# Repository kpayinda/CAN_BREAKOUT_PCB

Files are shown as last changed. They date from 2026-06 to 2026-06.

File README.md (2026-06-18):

# CAN Bus Development Board

A general-purpose breakout and development board featuring the **MCP2562FDT** CAN transceiver, designed for testing and system integration.

## Key Features
* **Transceiver:** MCP2562FDT-E/SN (supports CAN FD up to 5 Mbps).
* **Power Rails:** Dual-rail design ($V_{DD} = 5\text{V}$ for bus, $V_{IO} = 3.3\text{V}$ for logic compatibility).
* **Protection:** On-board TVS diodes for ESD protection and space for a Common-Mode Choke.
* **Termination:** Includes optional split termination ($2 \times 60\,\Omega$ with a center-tapped capacitor to GND).

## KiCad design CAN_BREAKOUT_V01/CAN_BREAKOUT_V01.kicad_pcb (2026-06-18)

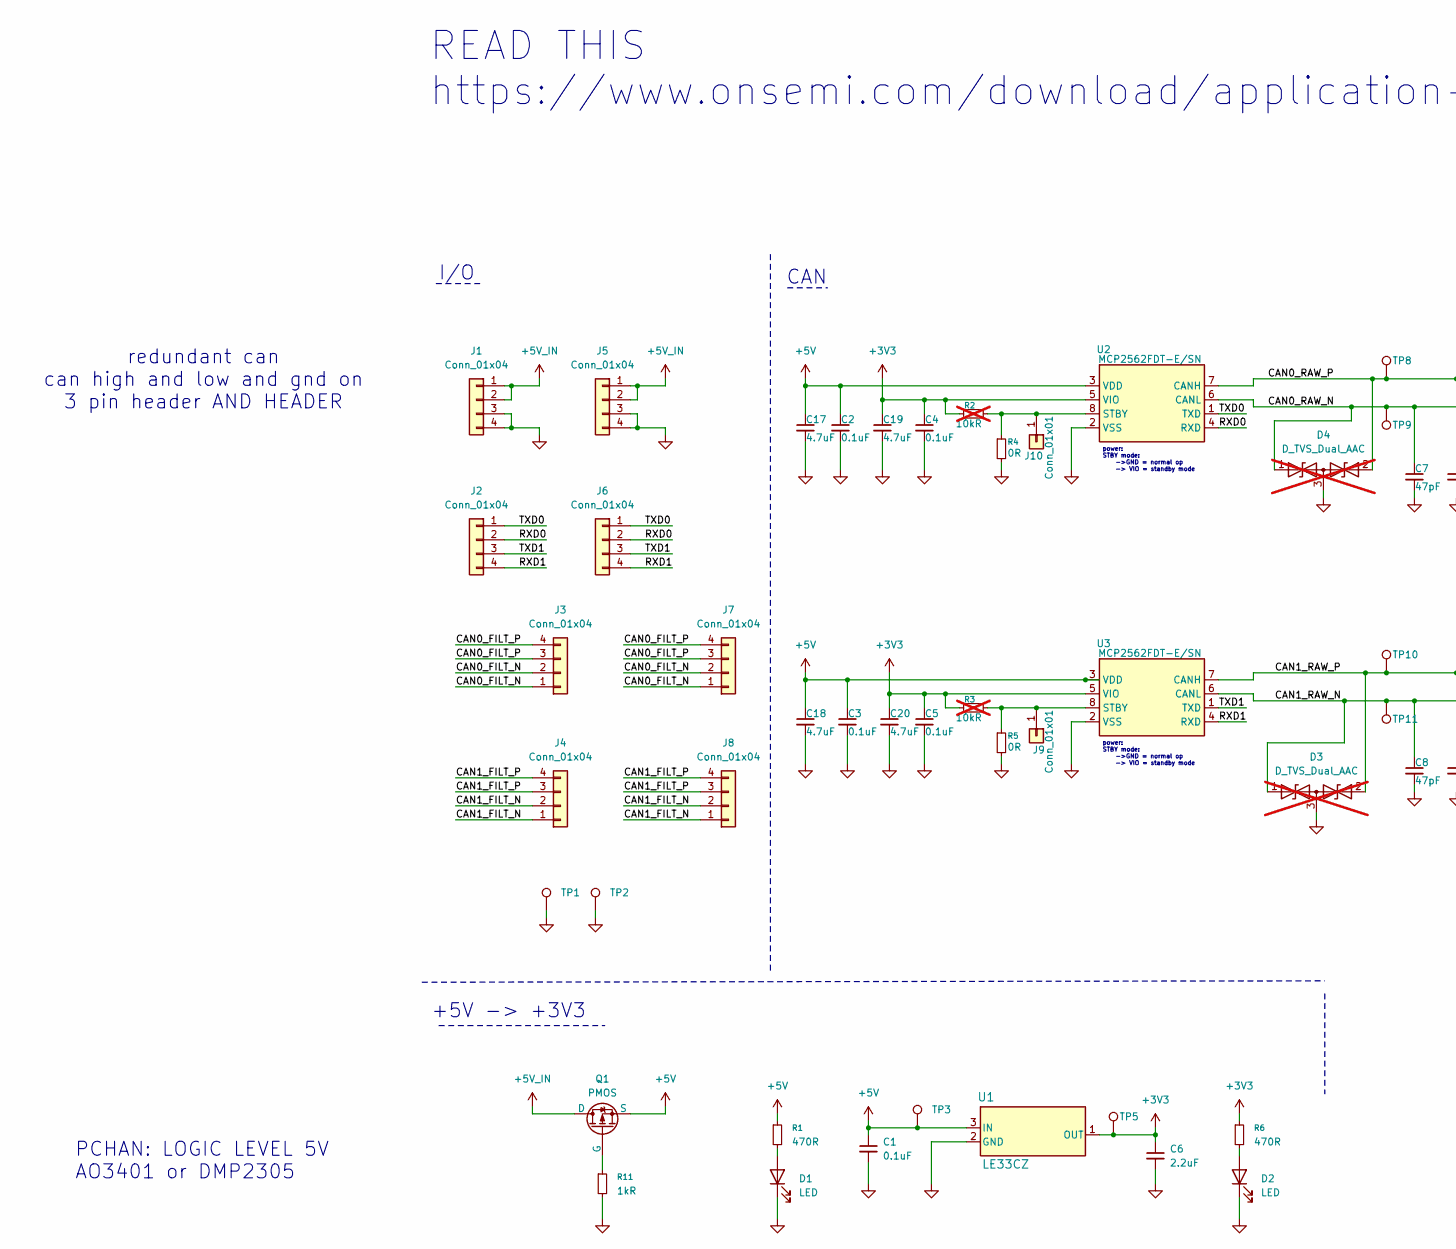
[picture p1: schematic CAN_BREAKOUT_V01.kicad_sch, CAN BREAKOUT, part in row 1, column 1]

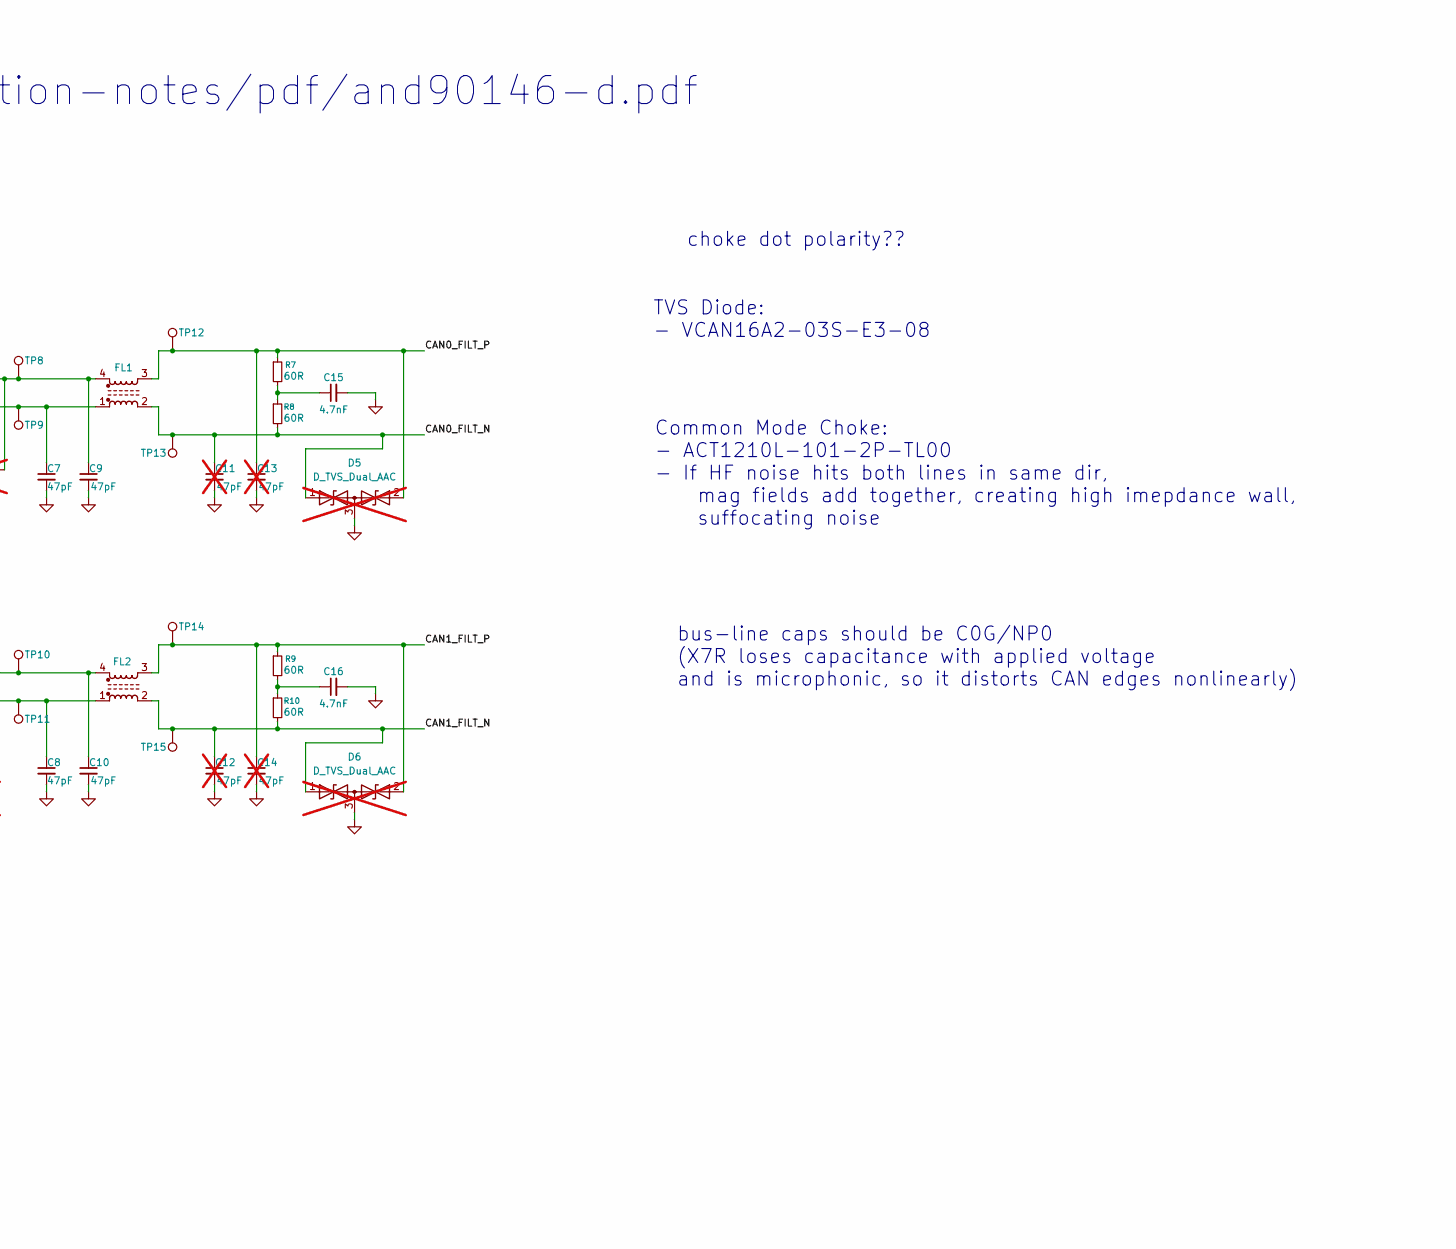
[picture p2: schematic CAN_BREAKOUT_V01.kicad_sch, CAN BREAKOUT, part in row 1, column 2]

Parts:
C1, C2, C3, C4, C5: 0.1uF; C_0603_1608Metric
C6: 2.2uF; C_0603_1608Metric
C7, C8, C9, C10: 47pF; C_0603_1608Metric
C11, C12, C13, C14: 47pF; C_0603_1608Metric; not fitted
C15, C16: 4.7nF; C_0603_1608Metric
C17, C18, C19, C20: 4.7uF; C_0603_1608Metric
D1, D2: LED; LED_0603_1608Metric
D3, D4, D5, D6: D_TVS_Dual_AAC; SOT-23-3; not fitted
FL1, FL2: Choke_CommonMode_FerriteCore_1243; L_CommonModeChoke_Coilcraft_1812CAN
J1, J2, J7, J8: Conn_01x04; Molex_PicoBlade_53261-0471_1x04-1MP_P1.25mm_Horizontal
J3, J4, J5, J6: Conn_01x04; PinHeader_1x04_P2.54mm_Vertical
J9, J10: Conn_01x01; PinHeader_1x01_P2.54mm_Vertical
Q1: PMOS; SOT-23-3
R1, R6: 470R; R_0603_1608Metric
R2, R3: 10kR; R_0603_1608Metric; not fitted
R4, R5: 0R; R_0603_1608Metric
R7, R8, R9, R10: 60R; R_0603_1608Metric
R11: 1kR; R_0603_1608Metric
TP1, TP2, TP3, TP5, TP8, TP9, TP10, TP11, TP12, TP13, TP14, TP15: TestPoint; TestPoint_Keystone_5000-5004_Miniature
U1: LE33CZ; TO-92
U2, U3: MCP2562FDT-E/SN; SOIC-8_3.9x4.9mm_P1.27mm

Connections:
+3V3: C4.1, C5.1, C6.1, C19.1, C20.1, R2.2, R3.2, R6.1, TP5.1, U1.1 (OUT), U2.5 (VIO), U3.5 (VIO)
+5V: C1.1, C2.1, C3.1, C17.1, C18.1, Q1.3 (S), R1.1, TP3.1, U1.3 (IN), U2.3 (VDD), U3.3 (VDD)
+5V_IN: J1.1, J1.2, J5.1, J5.2, Q1.1 (D)
/CAN0_FILT_N: C11.1, D5.1 (A1), FL1.2, J3.1, J3.2, J7.1, J7.2, R8.2, TP13.1
/CAN0_FILT_P: C13.1, D5.2 (A2), FL1.3, J3.3, J3.4, J7.3, J7.4, R7.1, TP12.1
/CAN0_RAW_N: C7.1, D4.1 (A1), FL1.1, TP9.1, U2.6 (CANL)
/CAN0_RAW_P: C9.1, D4.2 (A2), FL1.4, TP8.1, U2.7 (CANH)
/CAN1_FILT_N: C12.1, D6.1 (A1), FL2.2, J4.1, J4.2, J8.1, J8.2, R10.2, TP15.1
/CAN1_FILT_P: C14.1, D6.2 (A2), FL2.3, J4.3, J4.4, J8.3, J8.4, R9.1, TP14.1
/CAN1_RAW_N: C8.1, D3.1 (A1), FL2.1, TP11.1, U3.6 (CANL)
/CAN1_RAW_P: C10.1, D3.2 (A2), FL2.4, TP10.1, U3.7 (CANH)
/RXD0: J2.2, J6.2, U2.4 (RXD)
/RXD1: J2.4, J6.4, U3.4 (RXD)
/TXD0: J2.1, J6.1, U2.1 (TXD)
/TXD1: J2.3, J6.3, U3.1 (TXD)
GND: C1.2, C2.2, C3.2, C4.2, C5.2, C6.2, C7.2, C8.2, C9.2, C10.2, C11.2, C12.2, C13.2, C14.2, C15.2, C16.2, C17.2, C18.2, C19.2, C20.2, D1.1 (K), D2.1 (K), D3.3 (common), D4.3 (common), D5.3 (common), D6.3 (common), J1.3, J1.4, J5.3, J5.4, R4.2, R5.2, R11.2, TP1.1, TP2.1, U1.2 (GND), U2.2 (VSS), U3.2 (VSS)
unnamed: C15.1, R7.2, R8.1
unnamed: C16.1, R9.2, R10.1
unnamed: D1.2 (A), R1.2
unnamed: D2.2 (A), R6.2
unnamed: J9.1, R3.1, R5.1, U3.8 (STBY)
unnamed: J10.1, R2.1, R4.1, U2.8 (STBY)
unnamed: Q1.2 (G), R11.1

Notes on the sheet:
power: STBY mode: ->GND = normal op -> VIO = standby mode
READ THIS https://www.onsemi.com/download/application-notes/pdf/and90146-d.pdf
PCHAN: LOGIC LEVEL 5V AO3401 or DMP2305
Common Mode Choke: - ACT1210L-101-2P-TL00 - If HF noise hits both lines in same dir, mag fields add together, creating high imepdance wall, suffocating noise
I/O
CAN
choke dot polarity??
bus-line caps should be C0G/NP0 (X7R loses capacitance with applied voltage and is microphonic, so it distorts CAN edges nonlinearly)
+5V -> +3V3
TVS Diode: - VCAN16A2-03S-E3-08
redundant can can high and low and gnd on 3 pin header AND HEADER

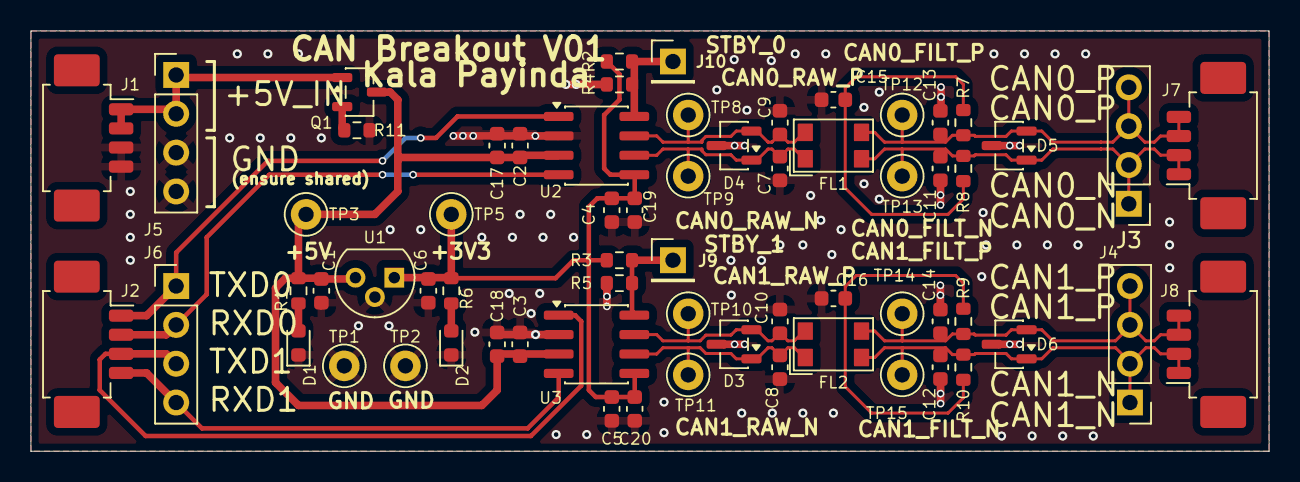
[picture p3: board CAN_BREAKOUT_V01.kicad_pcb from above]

Board: 2 copper layers, 81.0 x 27.5 mm, 65 parts (0 on the bottom side), 23 nets.

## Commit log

2026-06-04 pre-reviewed PCB
    [CAN_BREAKOUT_V01.kicad_pcb, CAN_BREAKOUT_V01.kicad_sch]
2026-06-04 Fix gitignore extension and untrack backup junk files
    [CAN_BREAKOUT_V01.kicad_pcb, CAN_BREAKOUT_V01.kicad_sch]
2026-06-04 added pcb files
    [CAN_BREAKOUT_V01.kicad_pcb, CAN_BREAKOUT_V01.kicad_sch]
2026-06-17 updated to break out SYNC pin to enable MCU control of redundancy channel; still getting text warnings, dont know how to change rules yet..
    [CAN_BREAKOUT_V01.kicad_pcb, CAN_BREAKOUT_V01.kicad_sch]
2026-06-18 ordering this V01 through JLCPCB
    [CAN_BREAKOUT_V01.kicad_pcb]
